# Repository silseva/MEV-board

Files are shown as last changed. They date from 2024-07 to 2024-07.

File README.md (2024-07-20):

# MEV board

Design files of the controller board used in the proof-of-concept setup of the [Multiple Emergency Ventilator project](https://mev.deib.polimi.it/).

The board has been designed to be coupled with an STM32F429 discovery board from ST Microelectronics (STM32F429I-DISC1) and serves a double puropose:
* controller for the closed-loop system regulating the bell-jar level;
* controller for the inspiration/expiration valves at bed side.

The design files are released in the Kicad 8.0 format under the [Creative Commons BY-NC-SA 4.0 license](https://creativecommons.org/licenses/by-nc-sa/4.0/).

**DISCLAIMER:** the hardware design made available in this repository has been made for a proof-of-concept setup. Therefore, it must not be considered safe for clinical use.

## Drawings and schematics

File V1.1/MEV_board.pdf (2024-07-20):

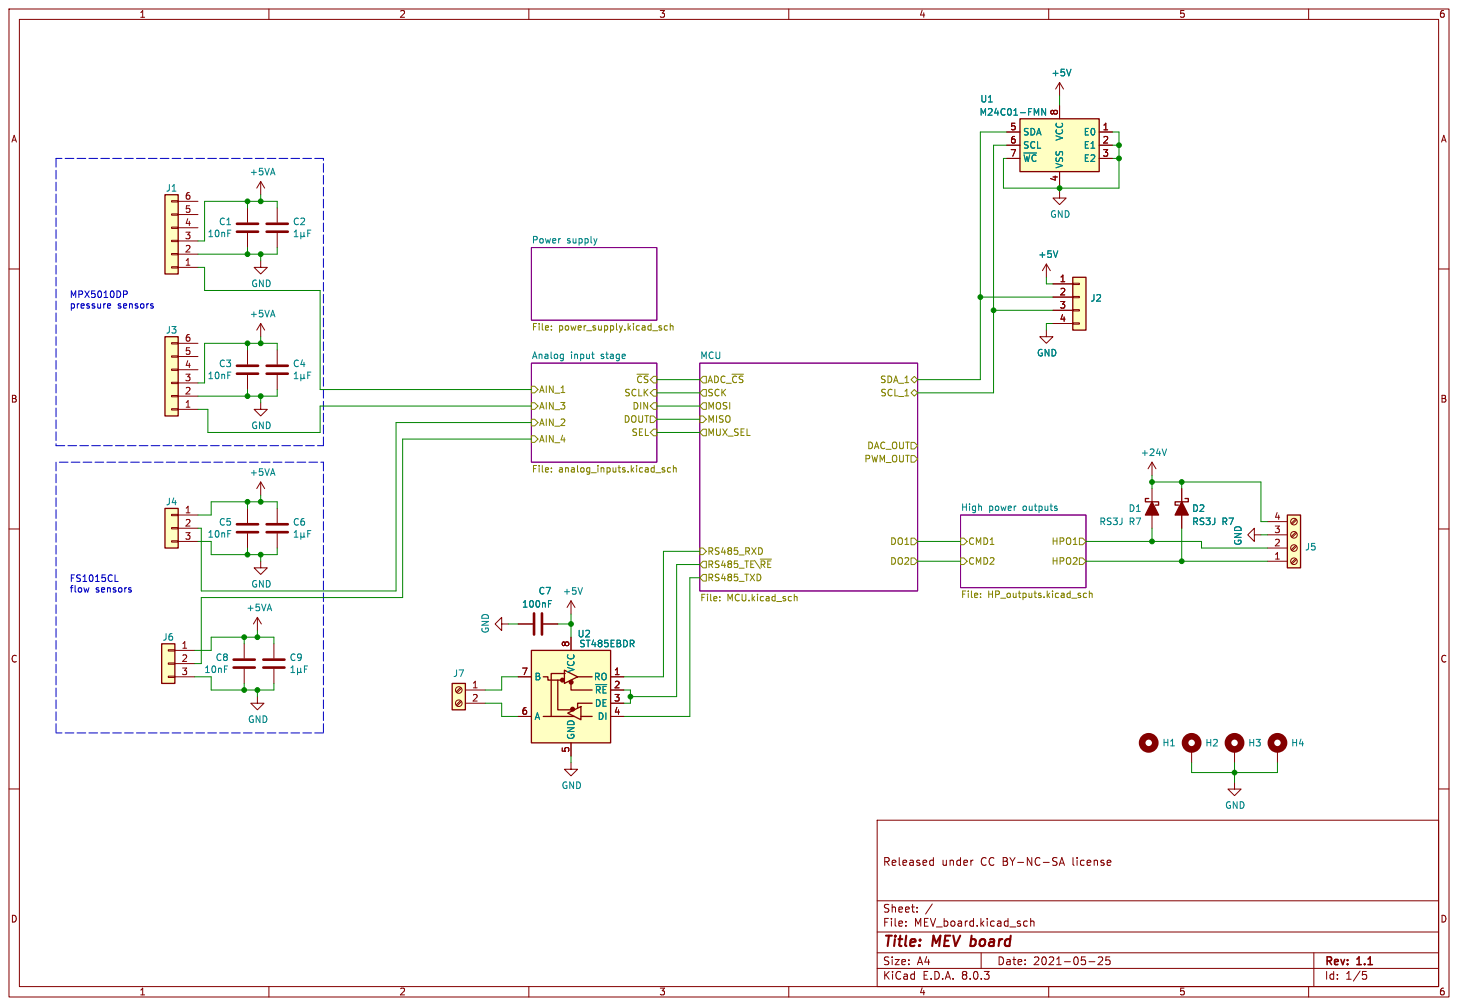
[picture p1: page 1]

SEL AIN_3 AIN_4 Analog input stage File: analog_inputs.kicad_sch Power supply File: power_supply.kicad_sch

SCL_1 SDA_1 SCK MOSI ADC_~{CS} MISO

Id: 1/5 Title: MEV board

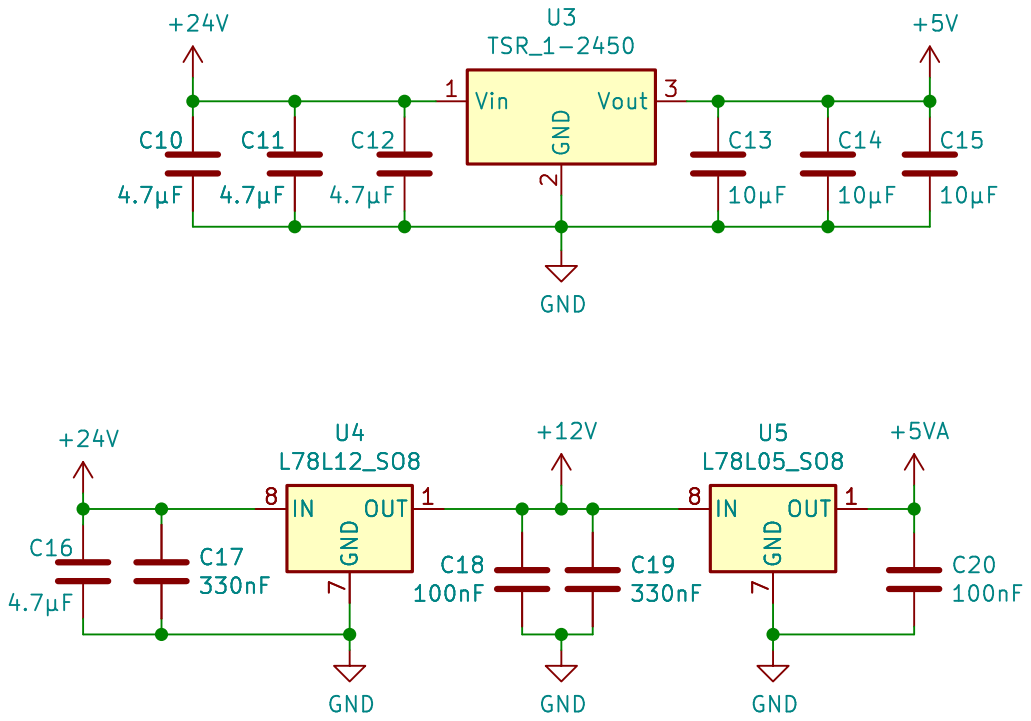
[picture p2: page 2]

Id: 2/5 Title: Power Supply

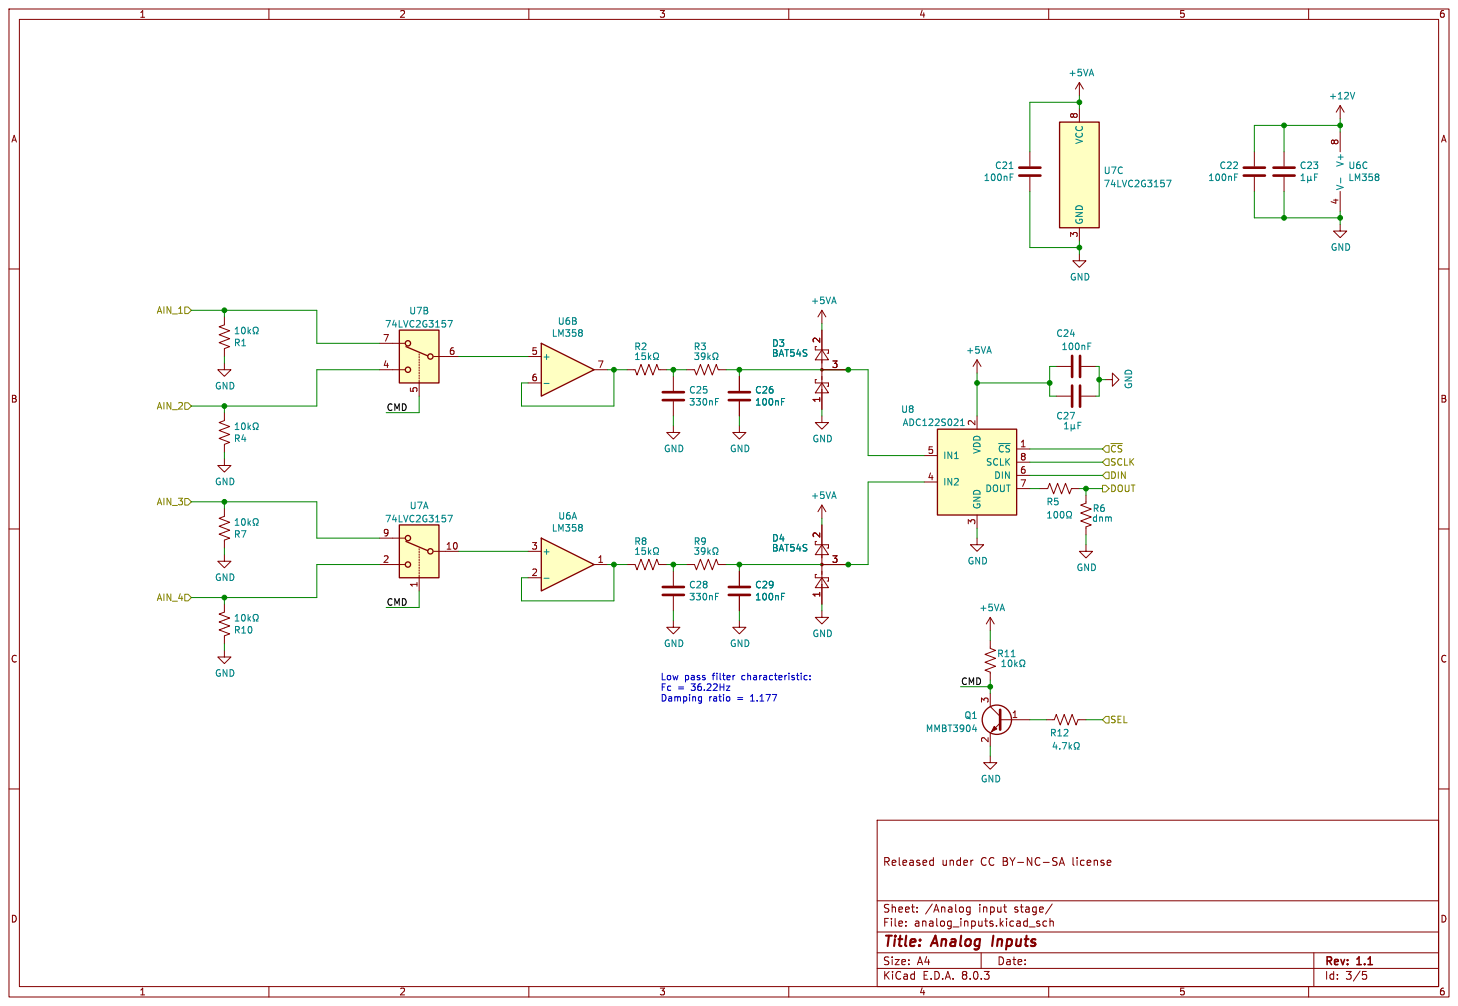
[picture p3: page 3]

Id: 3/5 Title: Analog Inputs

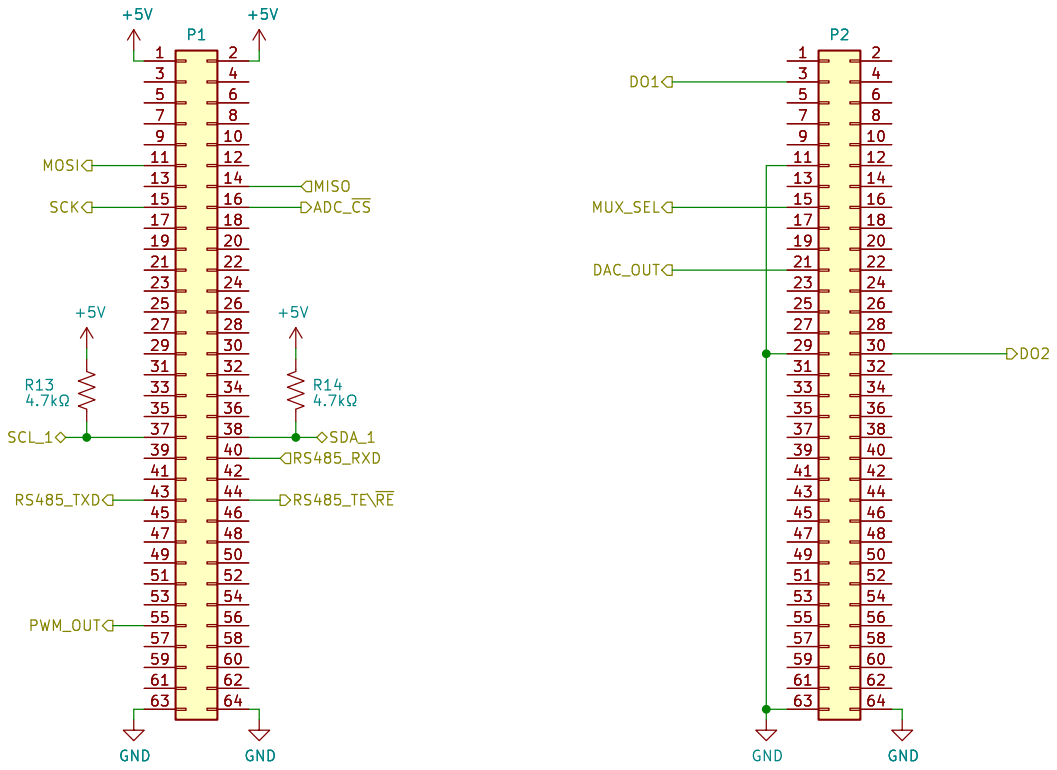
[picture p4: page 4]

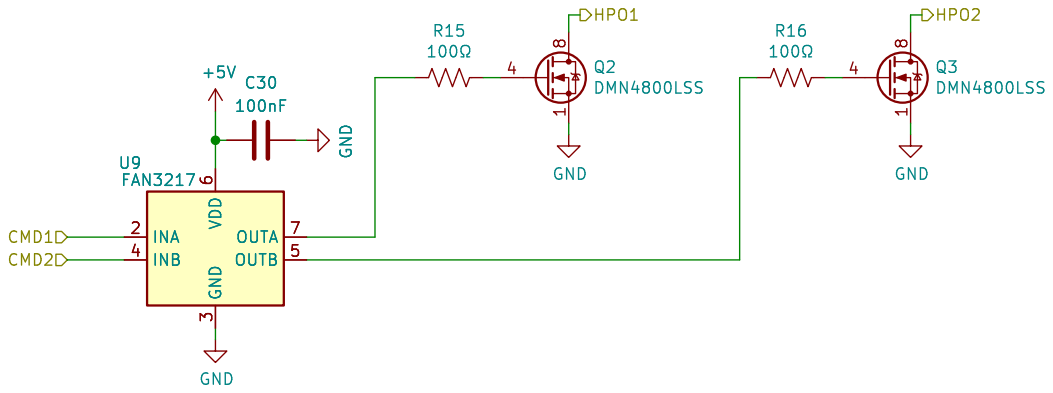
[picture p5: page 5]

Id: 5/5 Title: High Power Outputs

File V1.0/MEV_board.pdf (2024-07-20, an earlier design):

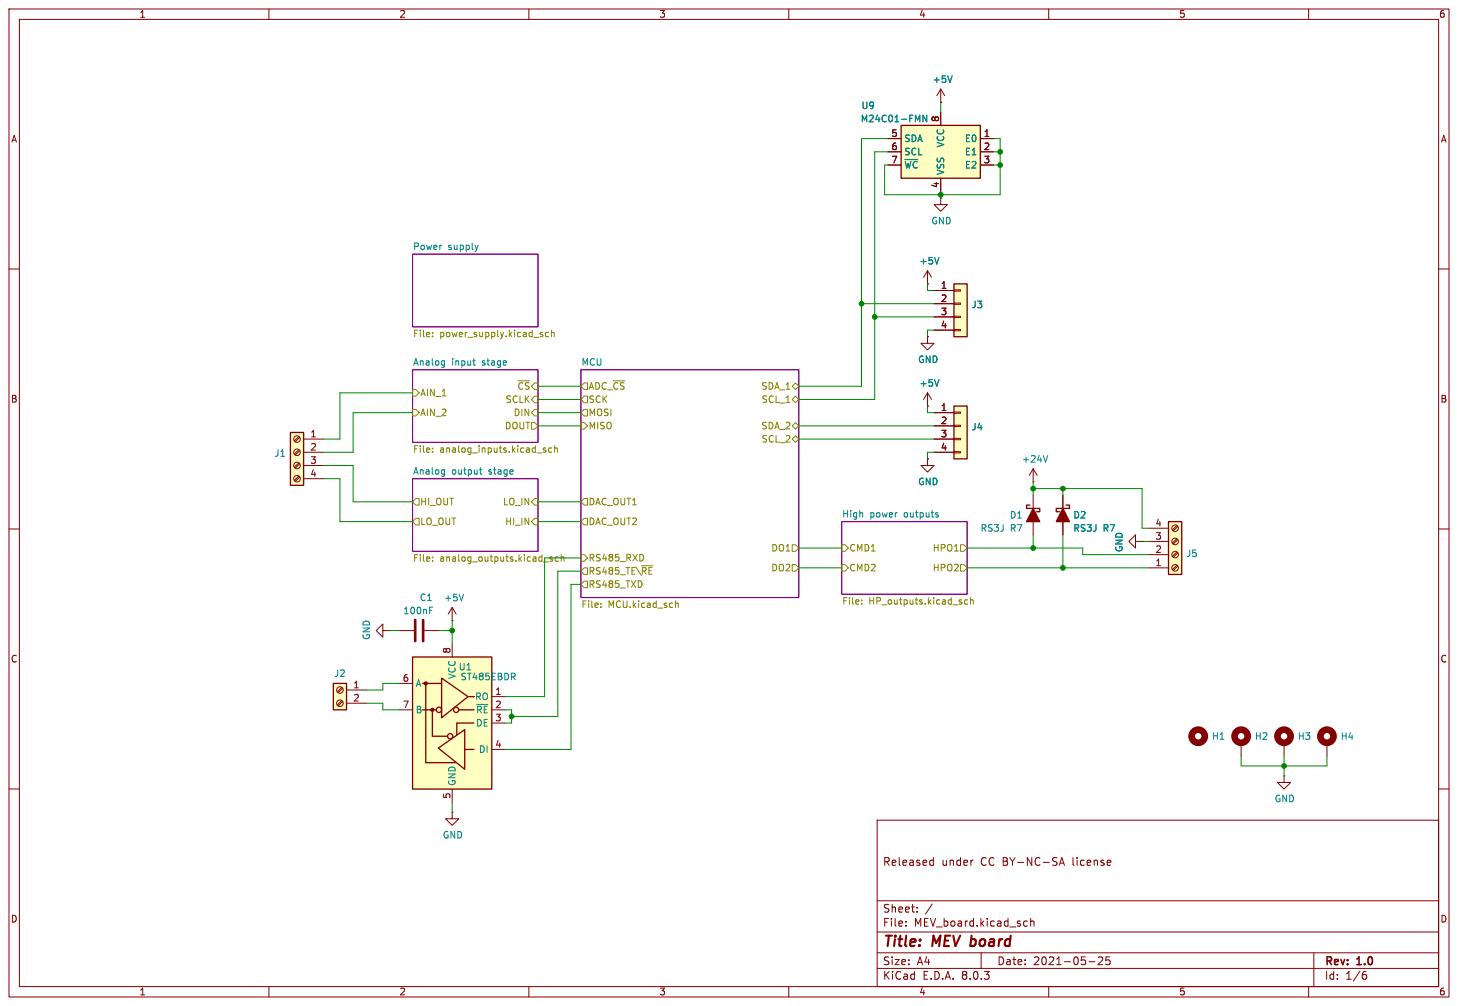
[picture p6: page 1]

Analog input stage File: analog_inputs.kicad_sch

Id: 1/6 Title: MEV board

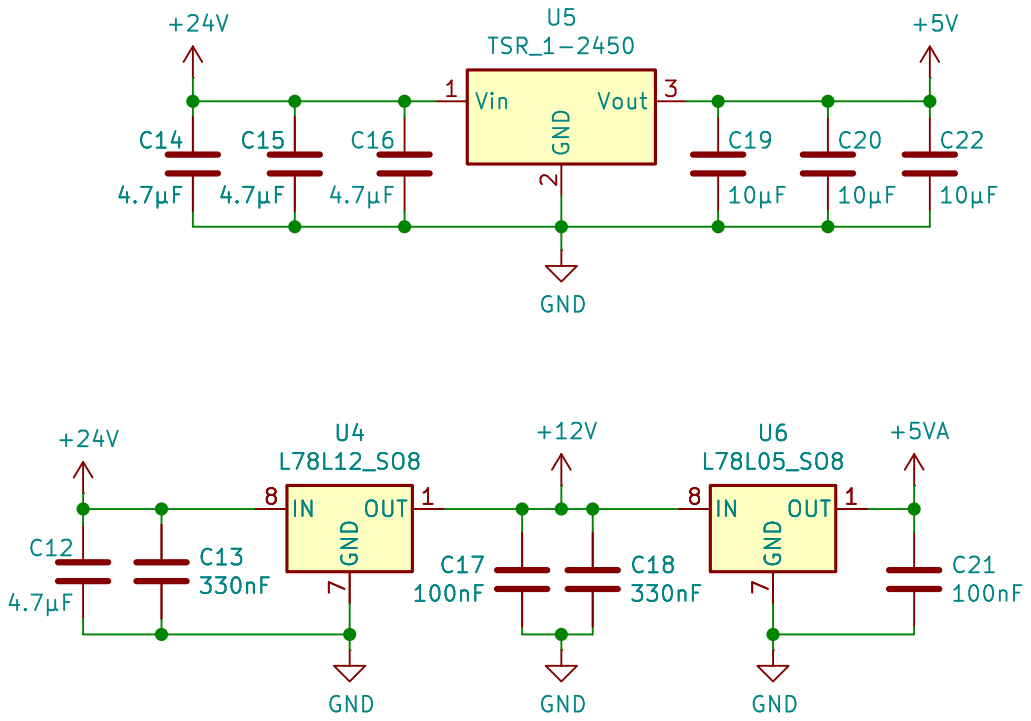
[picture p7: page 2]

Id: 2/6 Title: Power Supply

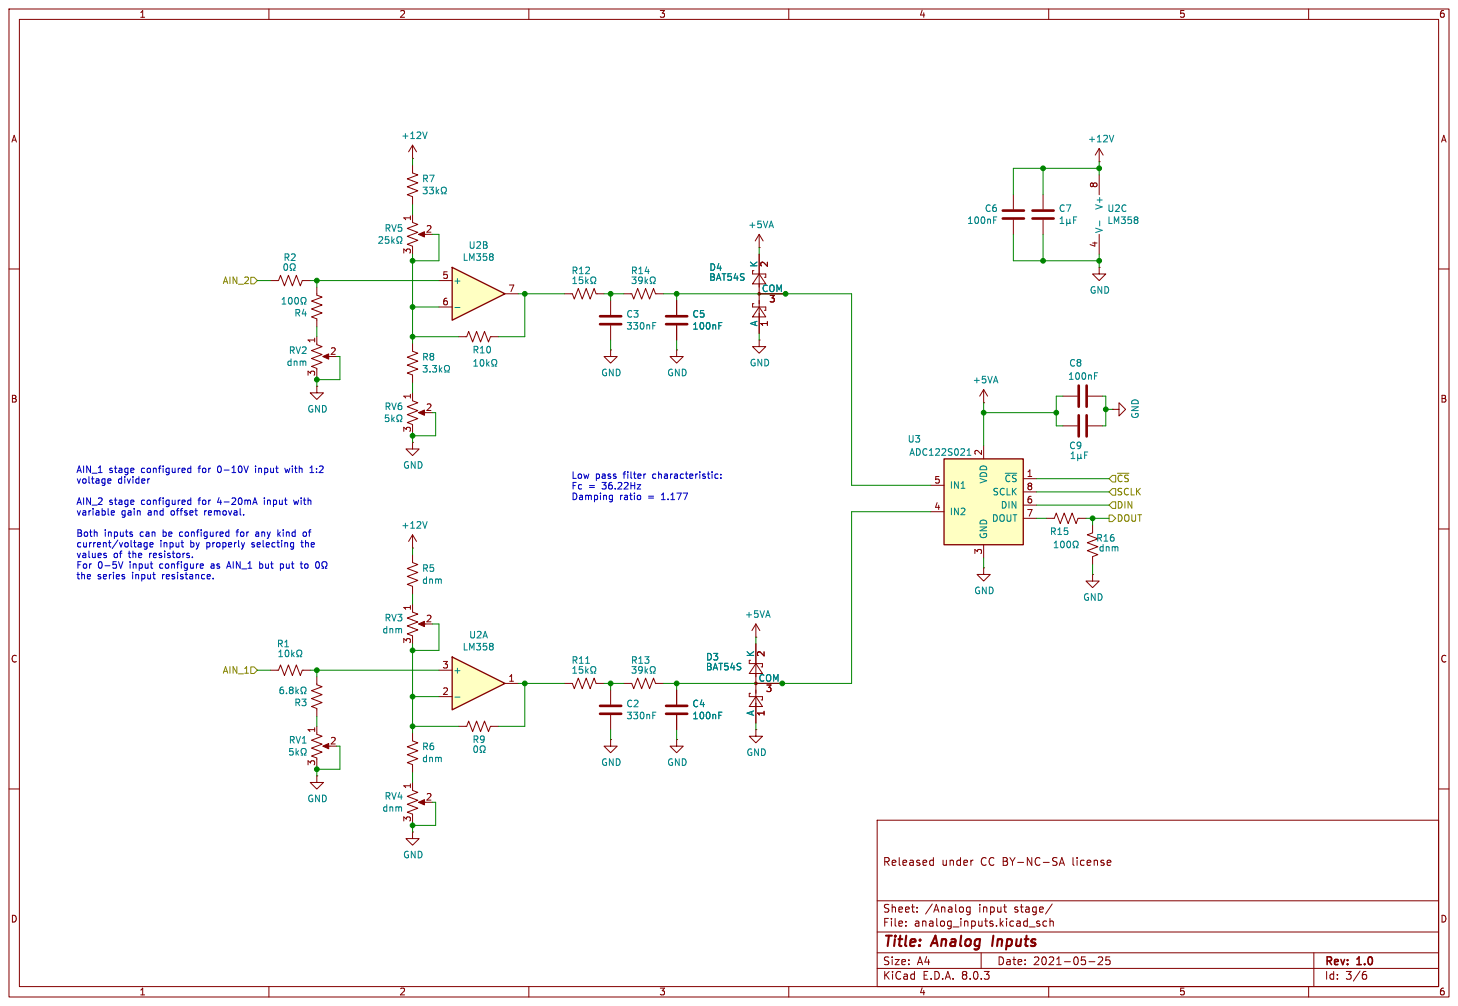
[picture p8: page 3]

Id: 3/6 Title: Analog Inputs

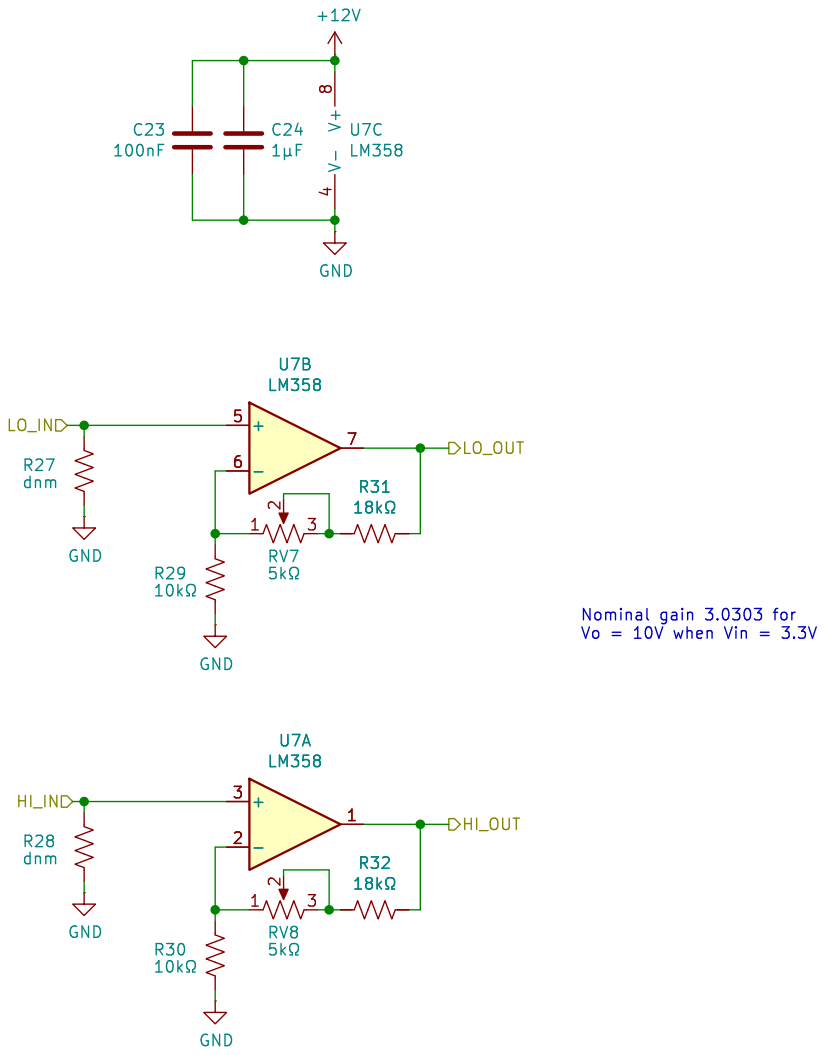
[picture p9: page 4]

Nominal gain 3.0303 for Vo = 10V when Vin = 3.3V U7B

Id: 4/6 Title: Analog Outputs

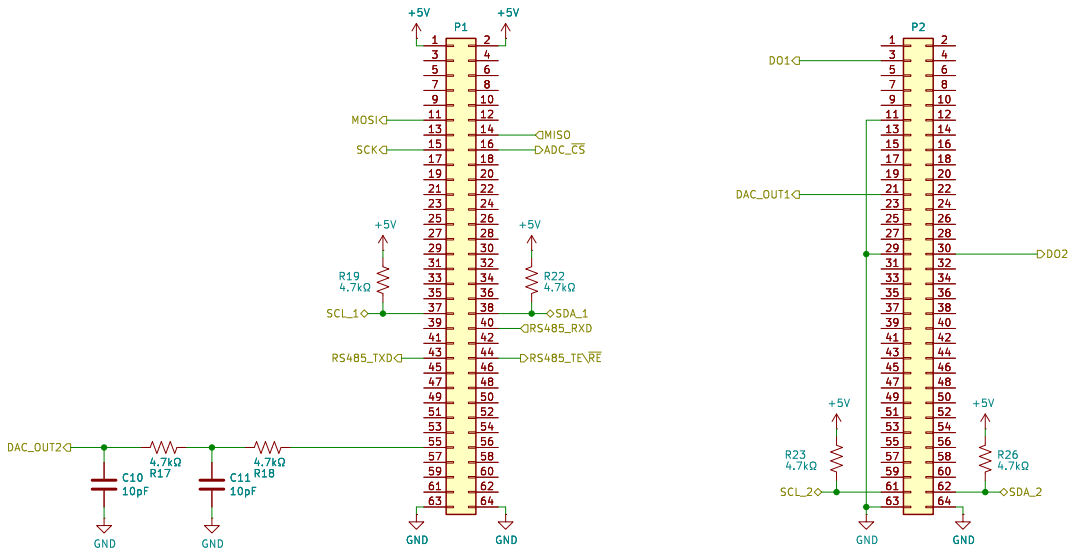
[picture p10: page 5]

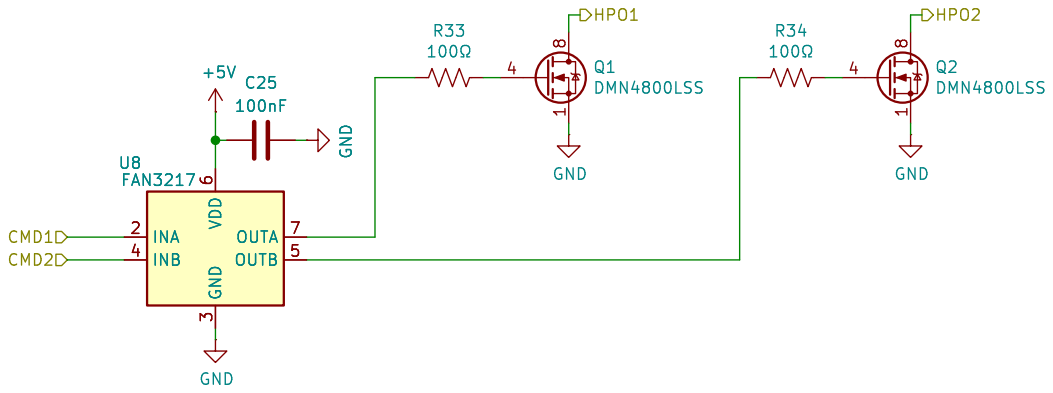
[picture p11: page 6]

Id: 6/6 Title: High Power Outputs

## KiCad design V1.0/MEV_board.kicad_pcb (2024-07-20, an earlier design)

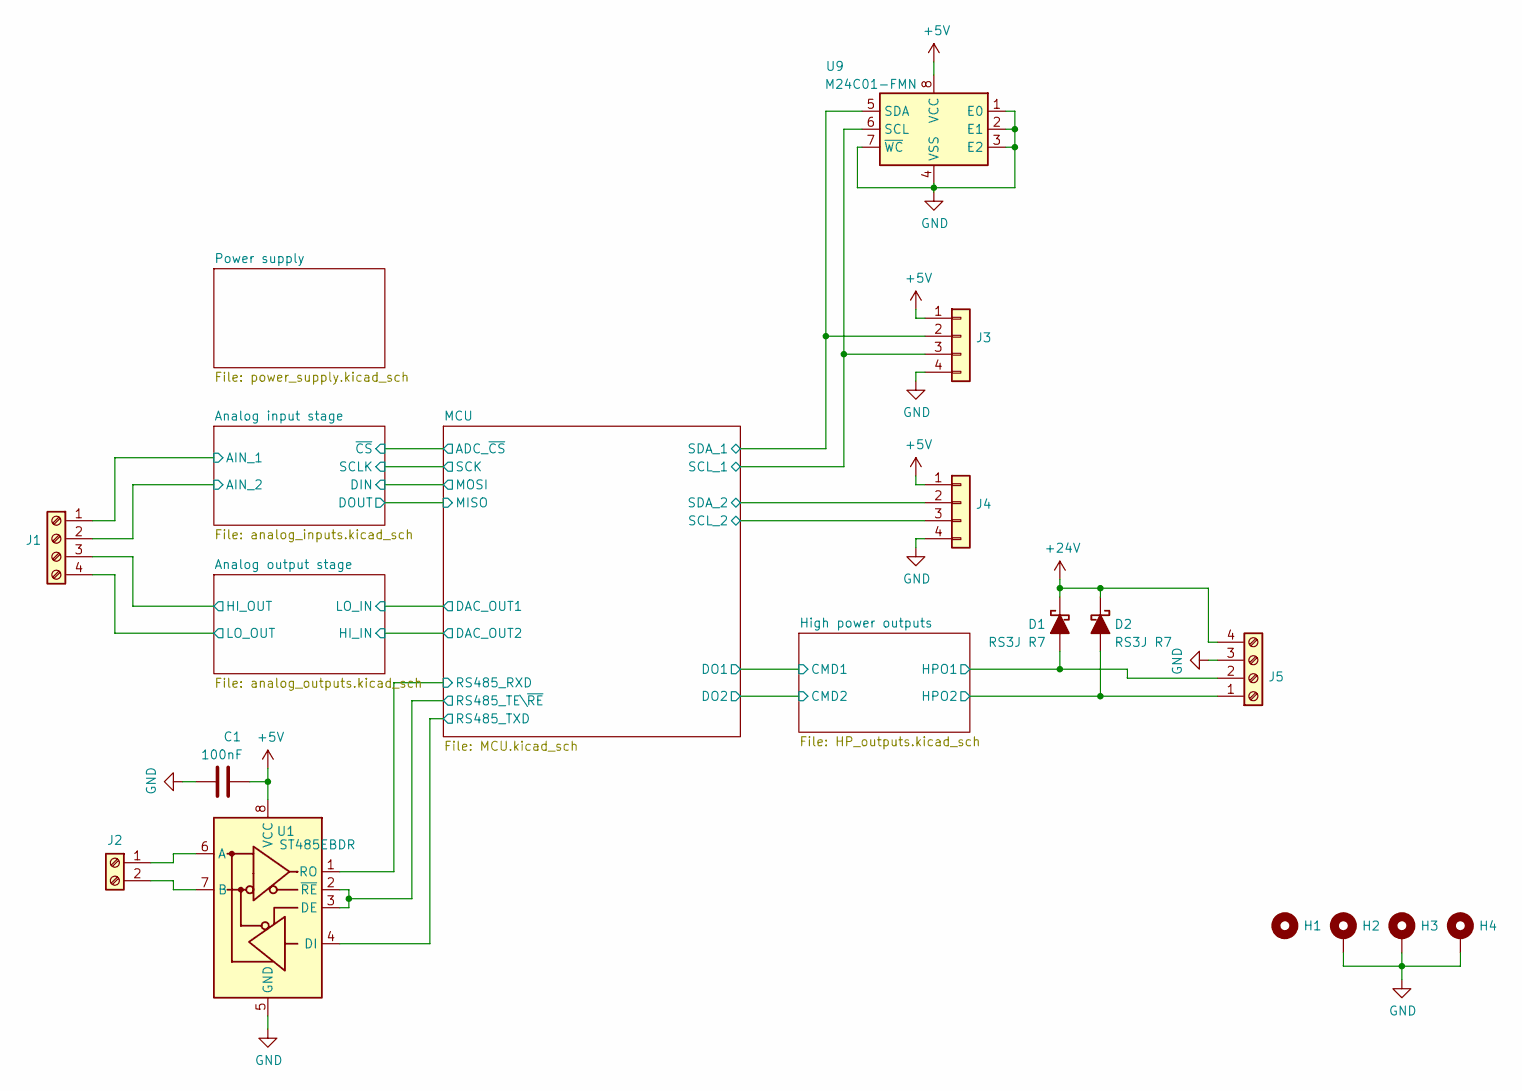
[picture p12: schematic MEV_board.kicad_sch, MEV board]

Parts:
C1: 100nF; C_0603_1608Metric_Pad1.08x0.95mm_HandSolder
D1, D2: RS3J R7; D_SMC_Handsoldering
H1, H2, H3, H4: MountingHole_3.2mm_M3_Pad_TopBottom
J1, J5: TerminalBlock_Phoenix_MKDS-1,5-4-5.08_1x04_P5.08mm_Horizont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
J2: TerminalBlock_Phoenix_MKDS-1,5-2-5.08_1x02_P5.08mm_Horizont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
J3, J4: PinHeader_1x04_P2.54mm_Vertical
U1: ST485EBDR; SOIC-8_3.9x4.9mm_P1.27mm
U9: M24C01-FMN; SOIC-8_3.9x4.9mm_P1.27mm

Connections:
+5V: C1.1, J3.1, J4.1, U1.8 (VCC), U9.8 (VCC); also elsewhere on the board
+24V: D1.1 (K), D2.1 (K), J5.4; also elsewhere on the board
/Analog input stage/AIN_1: J1.1; also elsewhere on the board
/Analog input stage/AIN_2: J1.2; also elsewhere on the board
/Analog output stage/HI_OUT: J1.3; also elsewhere on the board
/Analog output stage/LO_OUT: J1.4; also elsewhere on the board
/High power outputs/HPO1: D1.2 (A), J5.2; also elsewhere on the board
/High power outputs/HPO2: D2.2 (A), J5.1; also elsewhere on the board
/MCU/RS485_RXD: U1.1 (RO); also elsewhere on the board
/MCU/RS485_TE\~RE: U1.2 (~RE), U1.3 (DE); also elsewhere on the board
/MCU/RS485_TXD: U1.4 (DI); also elsewhere on the board
/MCU/SCL_1: J3.3, U9.6 (SCL); also elsewhere on the board
/MCU/SCL_2: J4.3; also elsewhere on the board
/MCU/SDA_1: J3.2, U9.5 (SDA); also elsewhere on the board
/MCU/SDA_2: J4.2; also elsewhere on the board
GND: C1.2, H2.1, H3.1, H4.1, J3.4, J4.4, J5.3, U1.5 (GND), U9.1 (E0), U9.2 (E1), U9.3 (E2), U9.4 (VSS), U9.7 (~WC); also elsewhere on the board

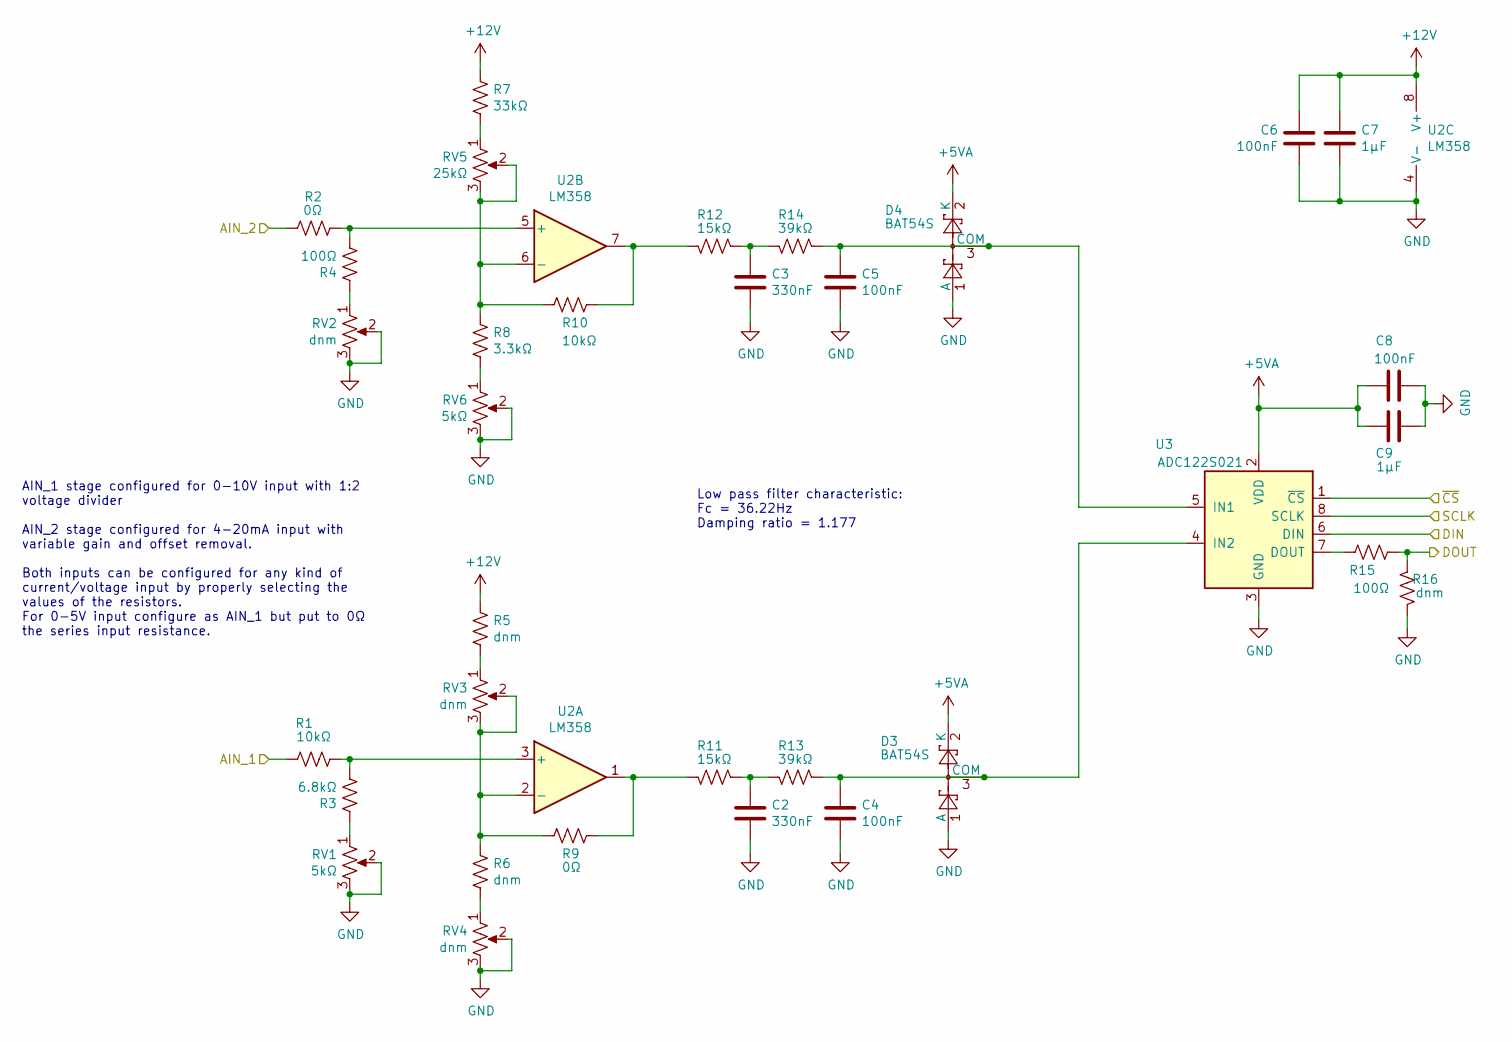
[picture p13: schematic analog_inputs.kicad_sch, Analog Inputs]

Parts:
C2, C3: 330nF; C_0805_2012Metric_Pad1.18x1.45mm_HandSolder
C4, C5: 100nF; C_0805_2012Metric_Pad1.18x1.45mm_HandSolder
C6, C8: 100nF; C_0603_1608Metric_Pad1.08x0.95mm_HandSolder
C7, C9: 1μF; C_0603_1608Metric_Pad1.08x0.95mm_HandSolder
D3, D4: BAT54S; SOT-23
R1, R10: 10kΩ; R_0805_2012Metric_Pad1.20x1.40mm_HandSolder
R2, R9: 0Ω; R_0805_2012Metric_Pad1.20x1.40mm_HandSolder
R3: 6.8kΩ; R_0805_2012Metric_Pad1.20x1.40mm_HandSolder
R4: 100Ω; R_0805_2012Metric_Pad1.20x1.40mm_HandSolder
R5, R6, R16: dnm; R_0805_2012Metric_Pad1.20x1.40mm_HandSolder
R7: 33kΩ; R_0805_2012Metric_Pad1.20x1.40mm_HandSolder
R8: 3.3kΩ; R_0805_2012Metric_Pad1.20x1.40mm_HandSolder
R11, R12: 15kΩ; R_0603_1608Metric_Pad0.98x0.95mm_HandSolder
R13, R14: 39kΩ; R_0603_1608Metric_Pad0.98x0.95mm_HandSolder
R15: 100Ω; R_0603_1608Metric_Pad0.98x0.95mm_HandSolder
RV1, RV6: 5kΩ; Potentiometer_Bourns_3296W_Vertical
RV2, RV3, RV4: dnm; Potentiometer_Bourns_3296W_Vertical
RV5: 25kΩ; Potentiometer_Bourns_3296W_Vertical
U2: LM358; SOIC-8_3.9x4.9mm_P1.27mm
U3: ADC122S021; VSSOP-8_3.0x3.0mm_P0.65mm

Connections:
+5VA: C8.1, C9.1, D3.2 (K), D4.2 (K), U3.2 (VDD); also elsewhere on the board
+12V: C6.2, C7.1, R5.1, R7.1, U2.8 (V+); also elsewhere on the board
/Analog input stage/AIN_1: R1.1; also elsewhere on the board
/Analog input stage/AIN_2: R2.1; also elsewhere on the board
/Analog input stage/DIN: U3.6 (DIN); also elsewhere on the board
/Analog input stage/DOUT: R15.2, R16.1; also elsewhere on the board
/MCU/ADC_~CS: U3.1 (~CS); also elsewhere on the board
/MCU/SCK: U3.8 (SCLK); also elsewhere on the board
GND: C2.2, C3.2, C4.2, C5.2, C6.1, C7.2, C8.2, C9.2, D3.1 (A), D4.1 (A), R16.2, RV1.2, RV1.3, RV2.2, RV2.3, RV4.2, RV4.3, RV6.2, RV6.3, U2.4 (V-), U3.3 (GND); also elsewhere on the board
unnamed: C2.1, R11.1, R13.2
unnamed: C3.1, R12.1, R14.2
unnamed: C4.1, D3.3 (COM), R13.1, U3.4 (IN2)
unnamed: C5.1, D4.3 (COM), R14.1, U3.5 (IN1)
unnamed: R1.2, R3.2, U2.3 (+)
unnamed: R2.2, R4.2, U2.5 (+)
unnamed: R3.1, RV1.1
unnamed: R4.1, RV2.1
unnamed: R5.2, RV3.1
unnamed: R6.1, R9.2, RV3.2, RV3.3, U2.2 (-)
unnamed: R6.2, RV4.1
unnamed: R7.2, RV5.1
unnamed: R8.2, RV6.1
unnamed: R10.1, R12.2, U2.7
unnamed: R8.1, R10.2, RV5.2, RV5.3, U2.6 (-)
unnamed: R9.1, R11.2, U2.1
unnamed: R15.1, U3.7 (DOUT)

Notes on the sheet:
AIN_1 stage configured for 0-10V input with 1:2 voltage divider AIN_2 stage configured for 4-20mA input with variable gain and offset removal. Both inputs can be configured for any kind of current/voltage input by properly selecting the values of the resistors. For 0-5V input configure as AIN_1 but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
Low pass filter characteristic: Fc = 36.22Hz Damping ratio = 1.177

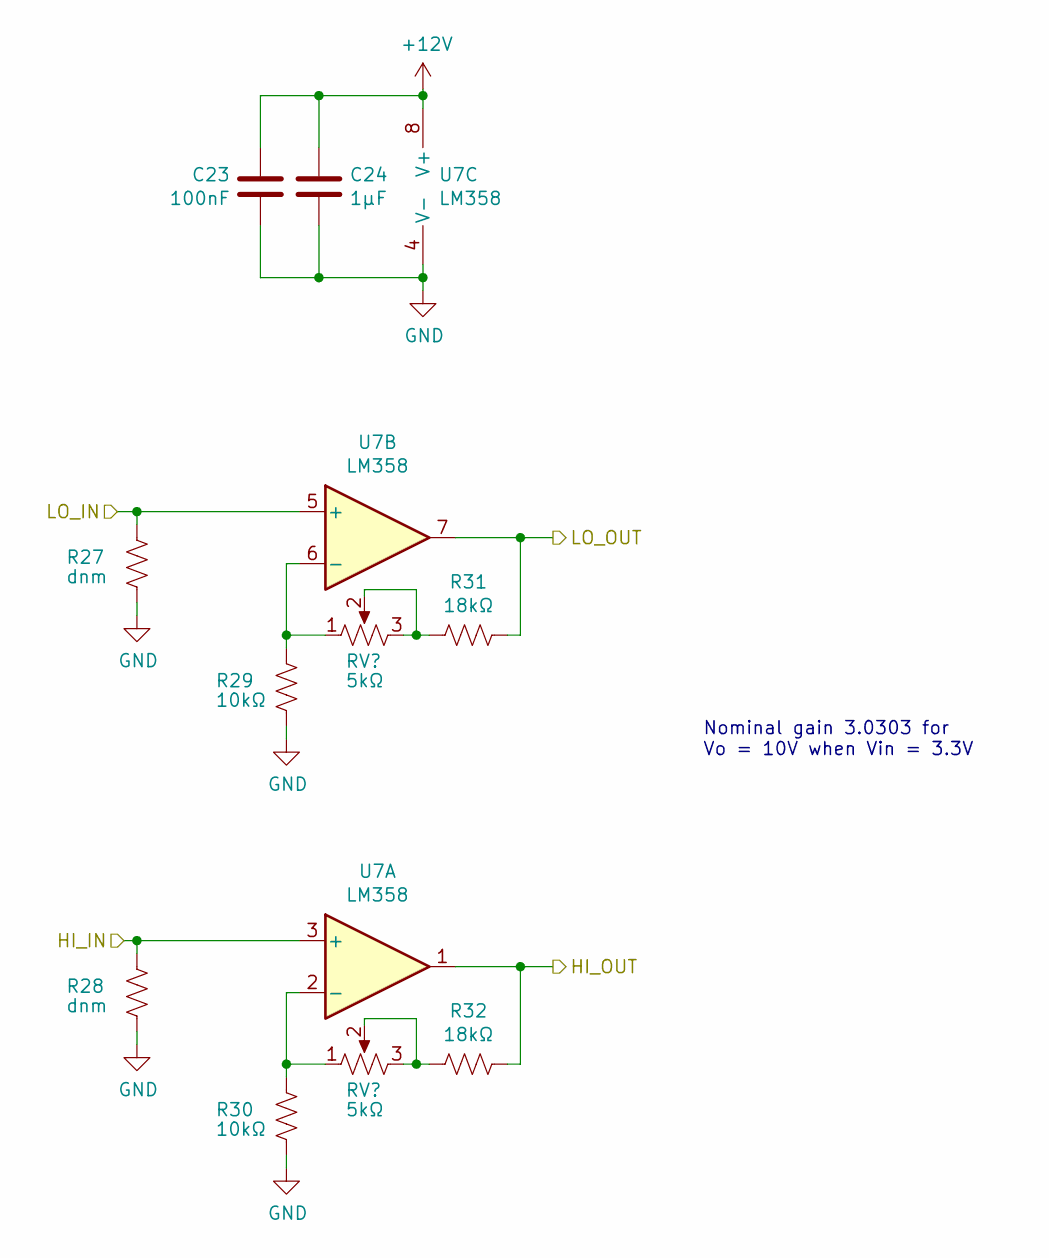
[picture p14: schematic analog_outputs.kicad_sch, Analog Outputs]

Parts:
C23: 100nF; C_0603_1608Metric_Pad1.08x0.95mm_HandSolder
C24: 1μF; C_0603_1608Metric_Pad1.08x0.95mm_HandSolder
R27, R28: dnm; R_0805_2012Metric_Pad1.20x1.40mm_HandSolder
R29, R30: 10kΩ; R_0805_2012Metric_Pad1.20x1.40mm_HandSolder
R31, R32: 18kΩ; R_0805_2012Metric_Pad1.20x1.40mm_HandSolder
RV7, RV8: 5kΩ; Potentiometer_Bourns_3296W_Vertical
U7: LM358; SOIC-8_3.9x4.9mm_P1.27mm

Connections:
+12V: C23.2, C24.1, U7.8 (V+); also elsewhere on the board
/Analog output stage/HI_OUT: R32.1, U7.1; also elsewhere on the board
/Analog output stage/LO_OUT: R31.1, U7.7; also elsewhere on the board
/MCU/DAC_OUT1: R27.1, U7.5 (+); also elsewhere on the board
/MCU/DAC_OUT2: R28.1, U7.3 (+); also elsewhere on the board
GND: C23.1, C24.2, R27.2, R28.2, R29.2, R30.2, U7.4 (V-); also elsewhere on the board
unnamed: R29.1, RV7.1, U7.6 (-)
unnamed: R30.1, RV8.1, U7.2 (-)
unnamed: R31.2, RV7.2, RV7.3
unnamed: R32.2, RV8.2, RV8.3

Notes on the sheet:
Nominal gain 3.0303 for Vo = 10V when Vin = 3.3V

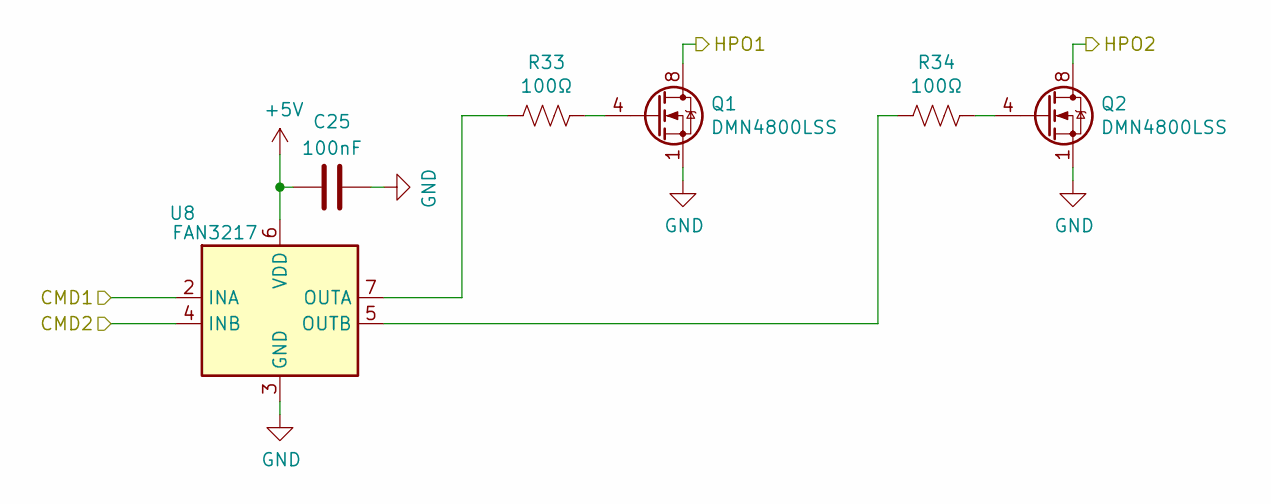
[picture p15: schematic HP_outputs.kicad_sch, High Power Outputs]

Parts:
C25: 100nF; C_0603_1608Metric_Pad1.08x0.95mm_HandSolder
Q1, Q2: DMN4800LSS; SOIC-8_3.9x4.9mm_P1.27mm
R33, R34: 100Ω; R_0603_1608Metric_Pad0.98x0.95mm_HandSolder
U8: FAN3217; SOIC-8_3.9x4.9mm_P1.27mm

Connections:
+5V: C25.1, U8.6 (VDD); also elsewhere on the board
/High power outputs/CMD1: U8.2 (INA); also elsewhere on the board
/High power outputs/CMD2: U8.4 (INB); also elsewhere on the board
/High power outputs/HPO1: Q1.5 (D), Q1.6 (D), Q1.7 (D), Q1.8 (D); also elsewhere on the board
/High power outputs/HPO2: Q2.5 (D), Q2.6 (D), Q2.7 (D), Q2.8 (D); also elsewhere on the board
GND: C25.2, Q1.1 (S), Q1.2 (S), Q1.3 (S), Q2.1 (S), Q2.2 (S), Q2.3 (S), U8.3 (GND); also elsewhere on the board
unnamed: Q1.4 (G), R33.1
unnamed: Q2.4 (G), R34.1
unnamed: R33.2, U8.7 (OUTA)
unnamed: R34.2, U8.5 (OUTB)

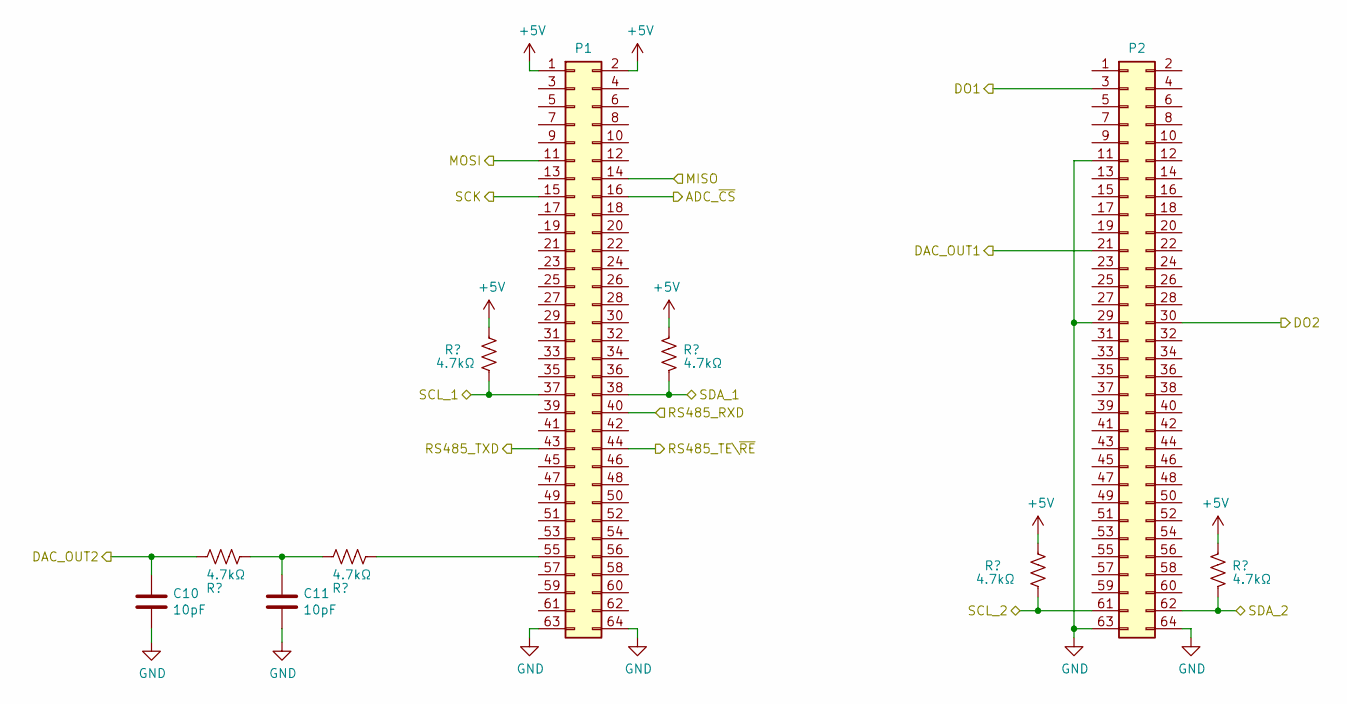
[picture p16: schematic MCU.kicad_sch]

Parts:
C10, C11: 10pF; C_0805_2012Metric_Pad1.18x1.45mm_HandSolder
P1, P2: PinHeader_2x32_P2.54mm_Vertical
R17, R18, R19, R22, R23, R26: 4.7kΩ; R_0603_1608Metric_Pad0.98x0.95mm_HandSolder

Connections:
+5V: P1.1, P1.2, R19.2, R22.2, R23.2, R26.2; also elsewhere on the board
/Analog input stage/DIN: P1.11; also elsewhere on the board
/Analog input stage/DOUT: P1.14; also elsewhere on the board
/High power outputs/CMD1: P2.3; also elsewhere on the board
/High power outputs/CMD2: P2.30; also elsewhere on the board
/MCU/ADC_~CS: P1.16; also elsewhere on the board
/MCU/DAC_OUT1: P2.21; also elsewhere on the board
/MCU/DAC_OUT2: C10.1, R17.2; also elsewhere on the board
/MCU/RS485_RXD: P1.40; also elsewhere on the board
/MCU/RS485_TE\~RE: P1.44; also elsewhere on the board
/MCU/RS485_TXD: P1.43; also elsewhere on the board
/MCU/SCK: P1.15; also elsewhere on the board
/MCU/SCL_1: P1.37, R19.1; also elsewhere on the board
/MCU/SCL_2: P2.61, R23.1; also elsewhere on the board
/MCU/SDA_1: P1.38, R22.1; also elsewhere on the board
/MCU/SDA_2: P2.62, R26.1; also elsewhere on the board
GND: C10.2, C11.2, P1.63, P1.64, P2.11, P2.29, P2.63, P2.64; also elsewhere on the board
unnamed: C11.1, R17.1, R18.2
unnamed: P1.55, R18.1

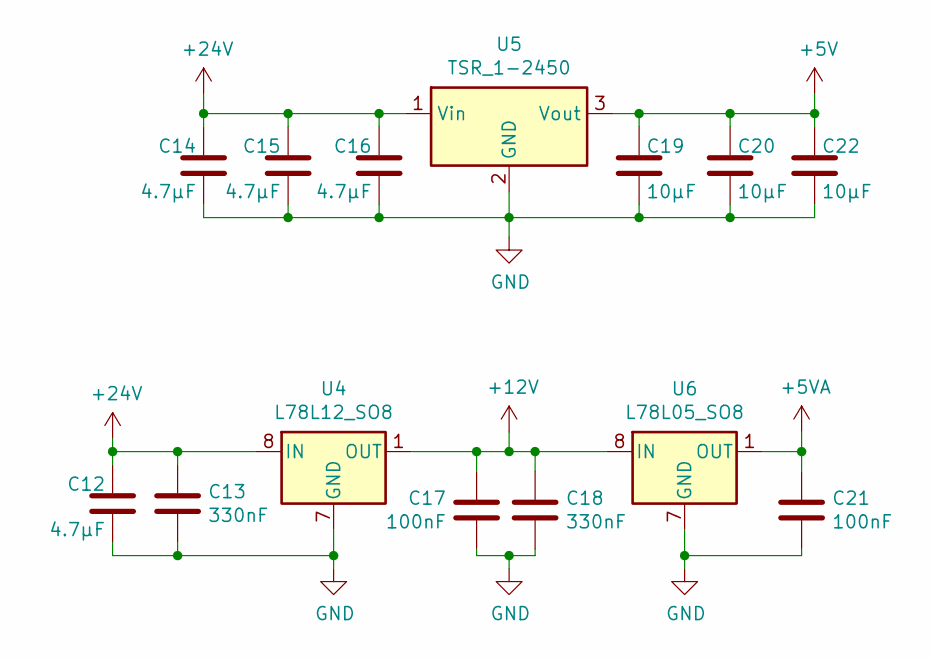
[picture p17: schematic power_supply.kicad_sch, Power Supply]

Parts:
C12, C14, C15, C16: 4.7μF; C_0805_2012Metric_Pad1.18x1.45mm_HandSolder
C13, C18: 330nF; C_0805_2012Metric_Pad1.18x1.45mm_HandSolder
C17, C21: 100nF; C_0603_1608Metric_Pad1.08x0.95mm_HandSolder
C19, C20, C22: 10μF; C_0805_2012Metric_Pad1.18x1.45mm_HandSolder
U4: L78L12_SO8; SOIC-8_3.9x4.9mm_P1.27mm
U5: TSR_1-2450; Converter_DCDC_TRACO_TSR-1_THT
U6: L78L05_SO8; SOIC-8_3.9x4.9mm_P1.27mm

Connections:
+5V: C19.2, C20.2, C22.2, U5.3 (Vout); also elsewhere on the board
+5VA: C21.2, U6.1 (OUT); also elsewhere on the board
+12V: C17.2, C18.2, U4.1 (OUT), U6.8 (IN); also elsewhere on the board
+24V: C12.2, C13.2, C14.2, C15.2, C16.2, U4.8 (IN), U5.1 (Vin); also elsewhere on the board
GND: C12.1, C13.1, C14.1, C15.1, C16.1, C17.1, C18.1, C19.1, C20.1, C21.1, C22.1, U4.2 (GND), U4.3 (GND), U4.6 (GND), U4.7 (GND), U5.2 (GND), U6.2 (GND), U6.3 (GND), U6.6 (GND), U6.7 (GND); also elsewhere on the board

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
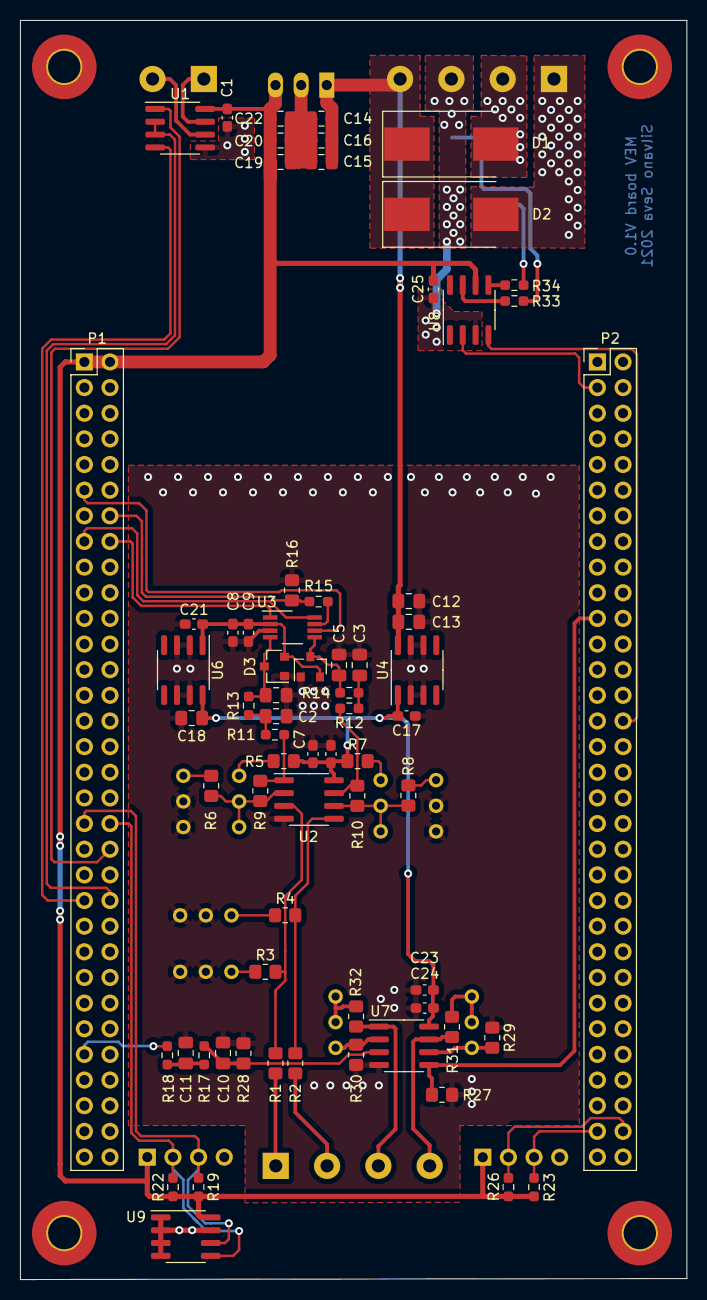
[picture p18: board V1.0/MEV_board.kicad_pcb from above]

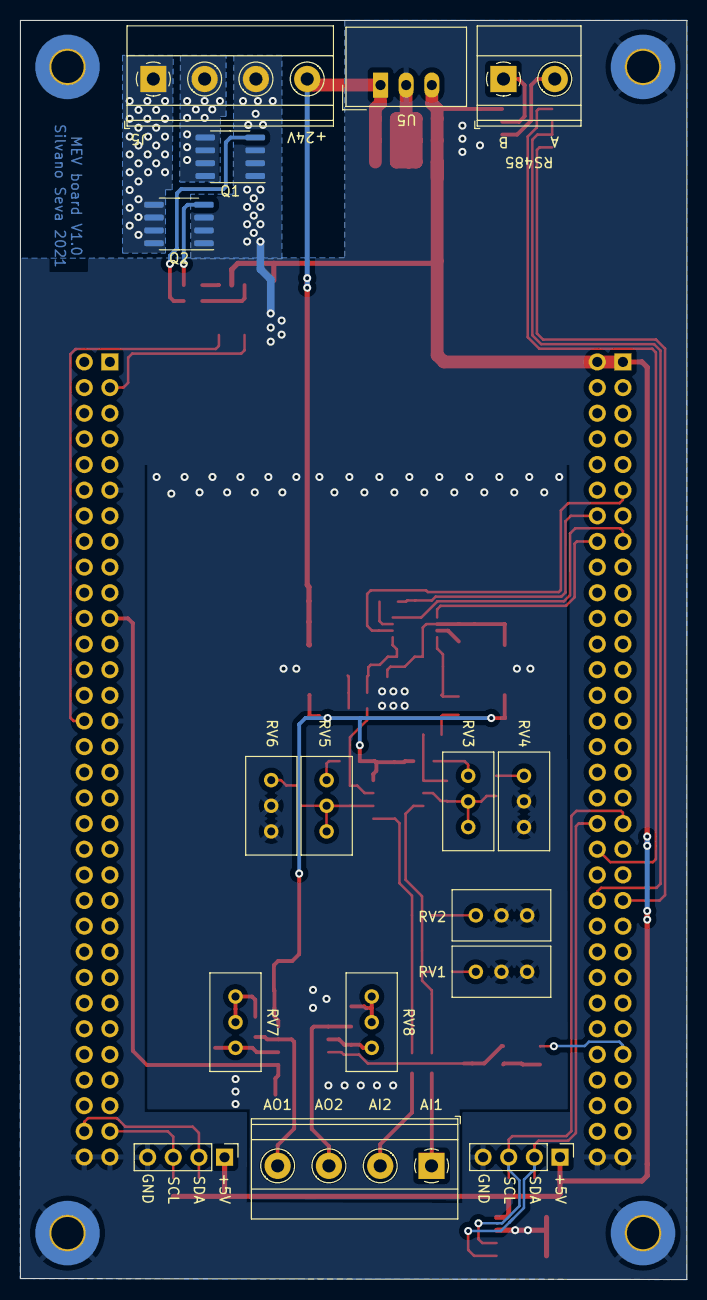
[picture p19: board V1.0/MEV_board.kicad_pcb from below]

Board: 2 copper layers, 66.0 x 124.7 mm, 89 parts (16 on the bottom side), 55 nets.

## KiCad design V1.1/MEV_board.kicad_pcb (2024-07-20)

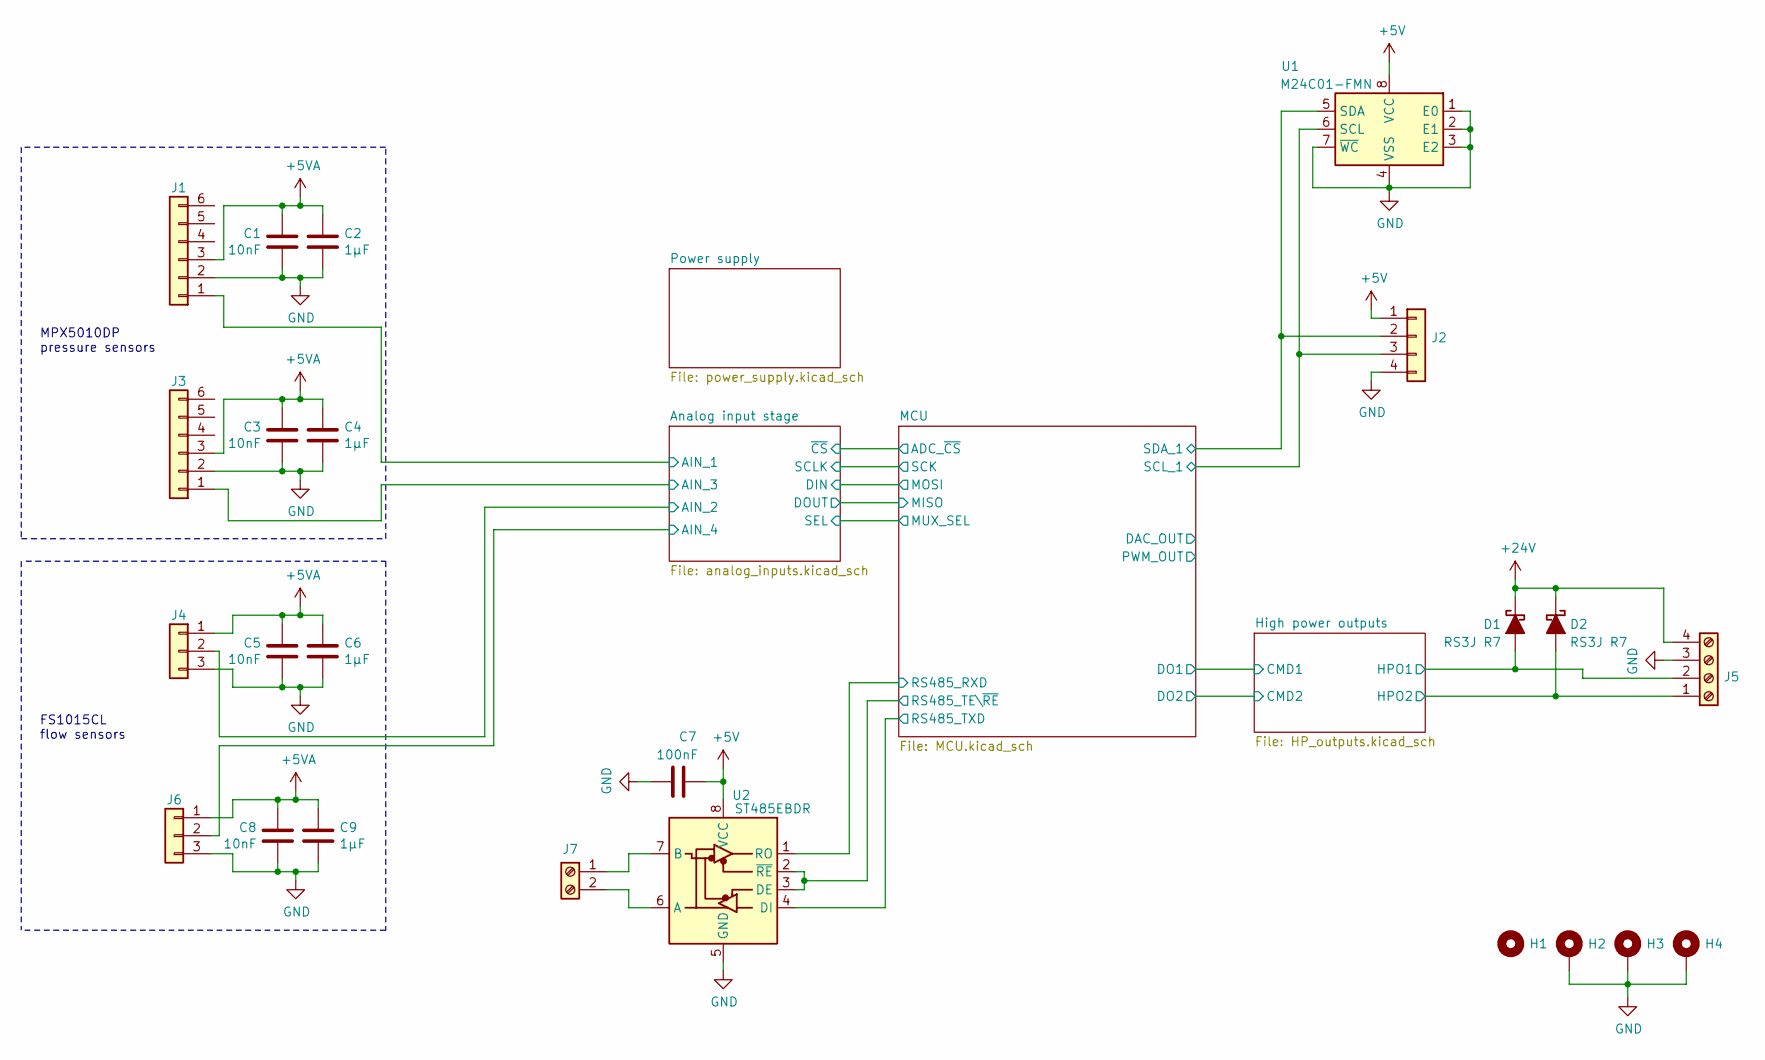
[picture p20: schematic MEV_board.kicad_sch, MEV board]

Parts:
C1, C3, C5, C8: 10nF; C_0603_1608Metric_Pad1.08x0.95mm_HandSolder
C2, C4, C6, C9: 1μF; C_0603_1608Metric_Pad1.08x0.95mm_HandSolder
C7: 100nF; C_0603_1608Metric_Pad1.08x0.95mm_HandSolder
D1, D2: RS3J R7; D_SMC_Handsoldering
H1, H2, H3, H4: MountingHole_3.2mm_M3_Pad_TopBottom
J1, J3: PinSocket_1x06_P2.54mm_Vertical
J2: PinHeader_1x04_P2.54mm_Vertical
J4, J6: Molex_KK-254_AE-6410-03A_1x03_P2.54mm_Vertical
J5: TerminalBlock_Phoenix_MKDS-1,5-4-5.08_1x04_P5.08mm_Horizont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
J7: TerminalBlock_Phoenix_MKDS-1,5-2-5.08_1x02_P5.08mm_Horizont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
U1: M24C01-FMN; SOIC-8_3.9x4.9mm_P1.27mm
U2: ST485EBDR; SOIC-8_3.9x4.9mm_P1.27mm

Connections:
+5V: C7.1, J2.1, U1.8 (VCC), U2.8 (VCC); also elsewhere on the board
+5VA: C1.2, C2.1, C3.2, C4.1, C5.2, C6.1, C8.2, C9.1, J1.3, J3.3, J4.1, J6.1; also elsewhere on the board
+24V: D1.1 (K), D2.1 (K), J5.4; also elsewhere on the board
/Analog input stage/AIN_1: J1.1; also elsewhere on the board
/Analog input stage/AIN_2: J4.2; also elsewhere on the board
/Analog input stage/AIN_3: J3.1; also elsewhere on the board
/Analog input stage/AIN_4: J6.2; also elsewhere on the board
/High power outputs/HPO1: D1.2 (A), J5.2; also elsewhere on the board
/High power outputs/HPO2: D2.2 (A), J5.1; also elsewhere on the board
/MCU/RS485_RXD: U2.1 (RO); also elsewhere on the board
/MCU/RS485_TE\~RE: U2.2 (~RE), U2.3 (DE); also elsewhere on the board
/MCU/RS485_TXD: U2.4 (DI); also elsewhere on the board
/MCU/SCL_1: J2.3, U1.6 (SCL); also elsewhere on the board
/MCU/SDA_1: J2.2, U1.5 (SDA); also elsewhere on the board
GND: C1.1, C2.2, C3.1, C4.2, C5.1, C6.2, C7.2, C8.1, C9.2, H2.1, H3.1, H4.1, J1.2, J2.4, J3.2, J4.3, J5.3, J6.3, U1.1 (E0), U1.2 (E1), U1.3 (E2), U1.4 (VSS), U1.7 (~WC), U2.5 (GND); also elsewhere on the board
unnamed: J7.1, U2.7 (B)
unnamed: J7.2, U2.6 (A)

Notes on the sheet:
FS1015CL flow sensors
MPX5010DP pressure sensors

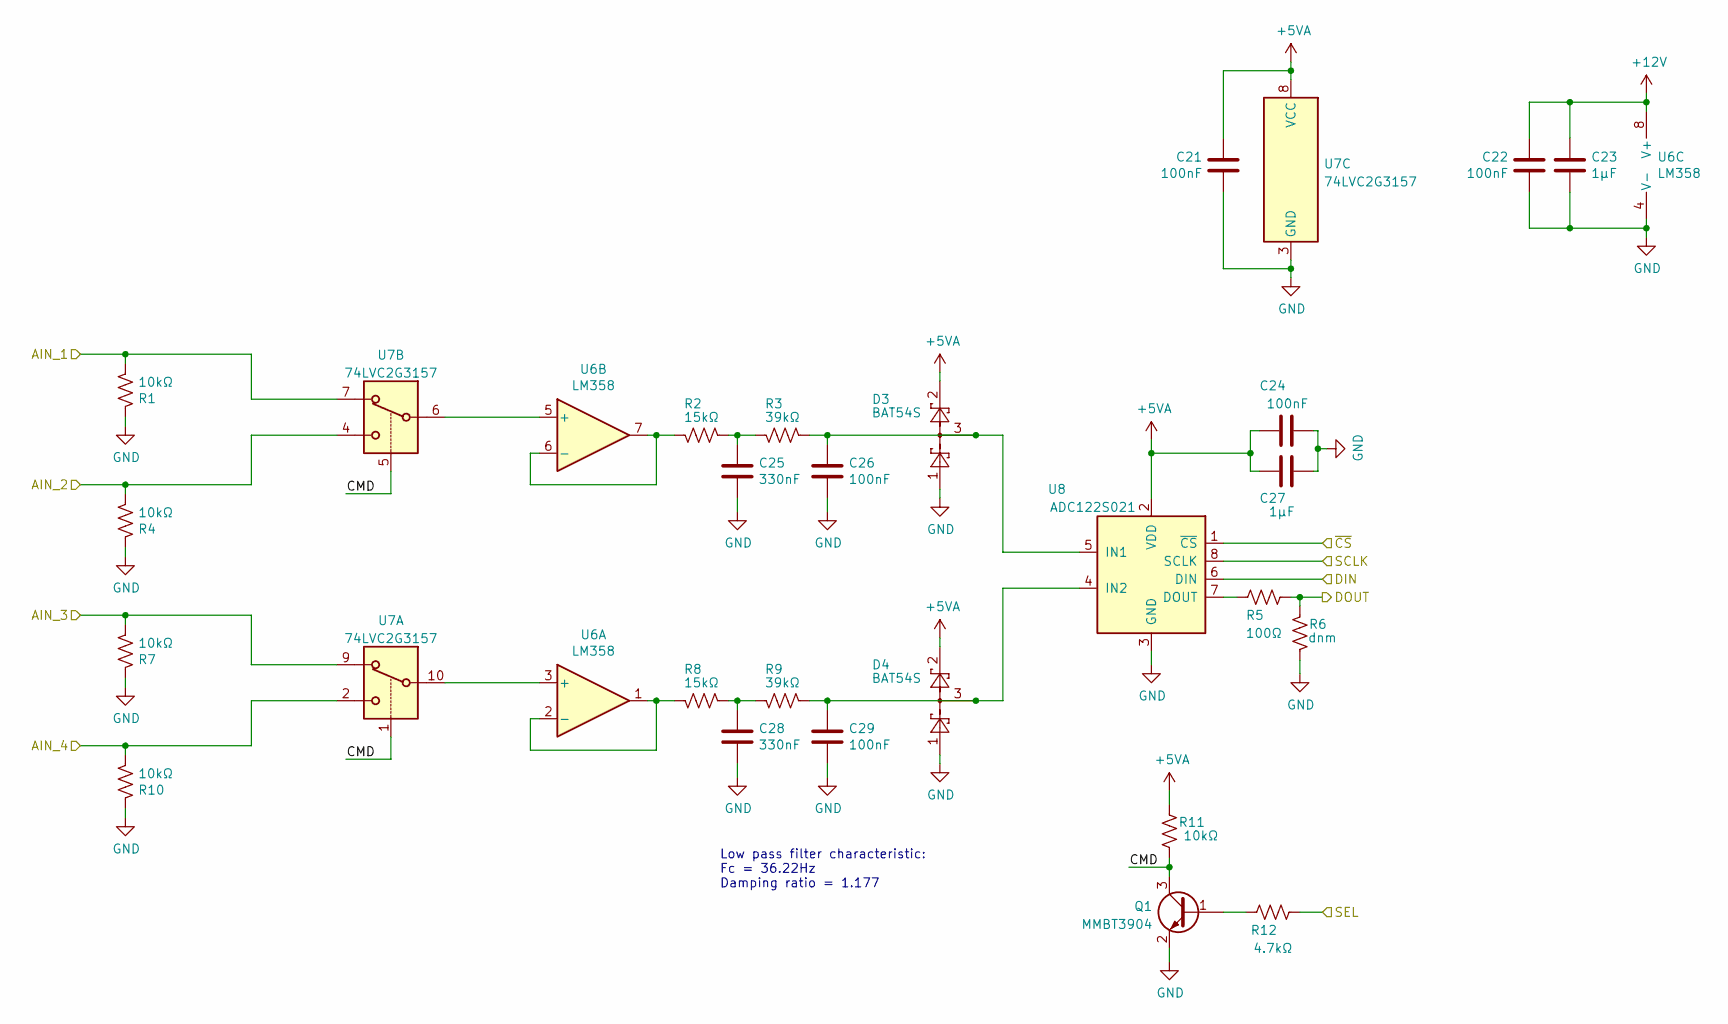
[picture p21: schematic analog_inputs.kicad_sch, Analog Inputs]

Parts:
C21, C22, C24, C26, C29: 100nF; C_0603_1608Metric_Pad1.08x0.95mm_HandSolder
C23, C27: 1μF; C_0603_1608Metric_Pad1.08x0.95mm_HandSolder
C25, C28: 330nF; C_0805_2012Metric_Pad1.18x1.45mm_HandSolder
D3, D4: BAT54S; SOT-23
Q1: MMBT3904; SOT-23
R1, R4, R7, R10, R11: 10kΩ; R_0805_2012Metric_Pad1.20x1.40mm_HandSolder
R2, R8: 15kΩ; R_0603_1608Metric_Pad0.98x0.95mm_HandSolder
R3, R9: 39kΩ; R_0603_1608Metric_Pad0.98x0.95mm_HandSolder
R5: 100Ω; R_0603_1608Metric_Pad0.98x0.95mm_HandSolder
R6: dnm; R_0805_2012Metric_Pad1.20x1.40mm_HandSolder
R12: 4.7kΩ; R_0603_1608Metric_Pad0.98x0.95mm_HandSolder
U6: LM358; SOIC-8_3.9x4.9mm_P1.27mm
U7: 74LVC2G3157; TSSOP-10_3x3mm_P0.5mm
U8: ADC122S021; VSSOP-8_3.0x3.0mm_P0.65mm

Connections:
+5VA: C21.2, C24.1, C27.1, D3.2, D4.2, R11.2, U7.8 (VCC), U8.2 (VDD); also elsewhere on the board
+12V: C22.2, C23.1, U6.8 (V+); also elsewhere on the board
/Analog input stage/AIN_1: R1.2, U7.7; also elsewhere on the board
/Analog input stage/AIN_2: R4.2, U7.4; also elsewhere on the board
/Analog input stage/AIN_3: R7.2, U7.9; also elsewhere on the board
/Analog input stage/AIN_4: R10.2, U7.2; also elsewhere on the board
/Analog input stage/CMD: Q1.3 (C), R11.1, U7.1, U7.5
/Analog input stage/DIN: U8.6 (DIN); also elsewhere on the board
/Analog input stage/DOUT: R5.2, R6.1; also elsewhere on the board
/Analog input stage/SCLK: U8.8 (SCLK); also elsewhere on the board
/Analog input stage/SEL: R12.2; also elsewhere on the board
/Analog input stage/~CS: U8.1 (~CS); also elsewhere on the board
GND: C21.1, C22.1, C23.2, C24.2, C25.2, C26.2, C27.2, C28.2, C29.2, D3.1, D4.1, Q1.2 (E), R1.1, R4.1, R6.2, R7.1, R10.1, U6.4 (V-), U7.3 (GND), U8.3 (GND); also elsewhere on the board
unnamed: C25.1, R2.1, R3.2
unnamed: C26.1, D3.3, R3.1, U8.5 (IN1)
unnamed: C28.1, R8.1, R9.2
unnamed: C29.1, D4.3, R9.1, U8.4 (IN2)
unnamed: Q1.1 (B), R12.1
unnamed: R2.2, U6.6 (-), U6.7
unnamed: R5.1, U8.7 (DOUT)
unnamed: R8.2, U6.1, U6.2 (-)
unnamed: U6.3 (+), U7.10
unnamed: U6.5 (+), U7.6

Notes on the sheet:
Low pass filter characteristic: Fc = 36.22Hz Damping ratio = 1.177

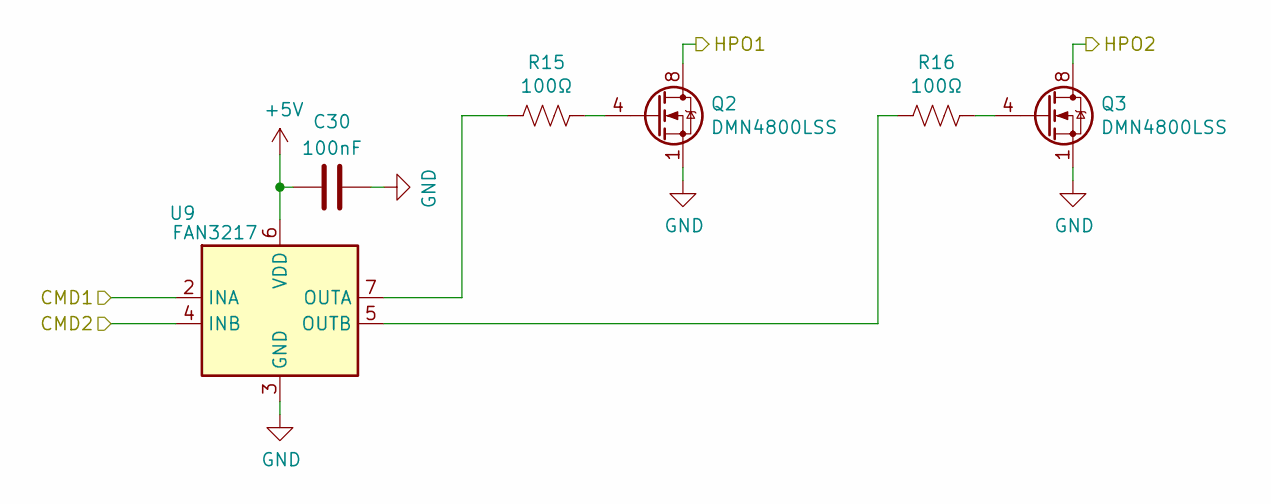
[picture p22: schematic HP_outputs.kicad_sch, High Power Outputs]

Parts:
C30: 100nF; C_0603_1608Metric_Pad1.08x0.95mm_HandSolder
Q2, Q3: DMN4800LSS; SOIC-8_3.9x4.9mm_P1.27mm
R15, R16: 100Ω; R_0603_1608Metric_Pad0.98x0.95mm_HandSolder
U9: FAN3217; SOIC-8_3.9x4.9mm_P1.27mm

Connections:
+5V: C30.1, U9.6 (VDD); also elsewhere on the board
/High power outputs/CMD1: U9.2 (INA); also elsewhere on the board
/High power outputs/CMD2: U9.4 (INB); also elsewhere on the board
/High power outputs/HPO1: Q2.5 (D), Q2.6 (D), Q2.7 (D), Q2.8 (D); also elsewhere on the board
/High power outputs/HPO2: Q3.5 (D), Q3.6 (D), Q3.7 (D), Q3.8 (D); also elsewhere on the board
GND: C30.2, Q2.1 (S), Q2.2 (S), Q2.3 (S), Q3.1 (S), Q3.2 (S), Q3.3 (S), U9.3 (GND); also elsewhere on the board
unnamed: Q2.4 (G), R15.1
unnamed: Q3.4 (G), R16.1
unnamed: R15.2, U9.7 (OUTA)
unnamed: R16.2, U9.5 (OUTB)

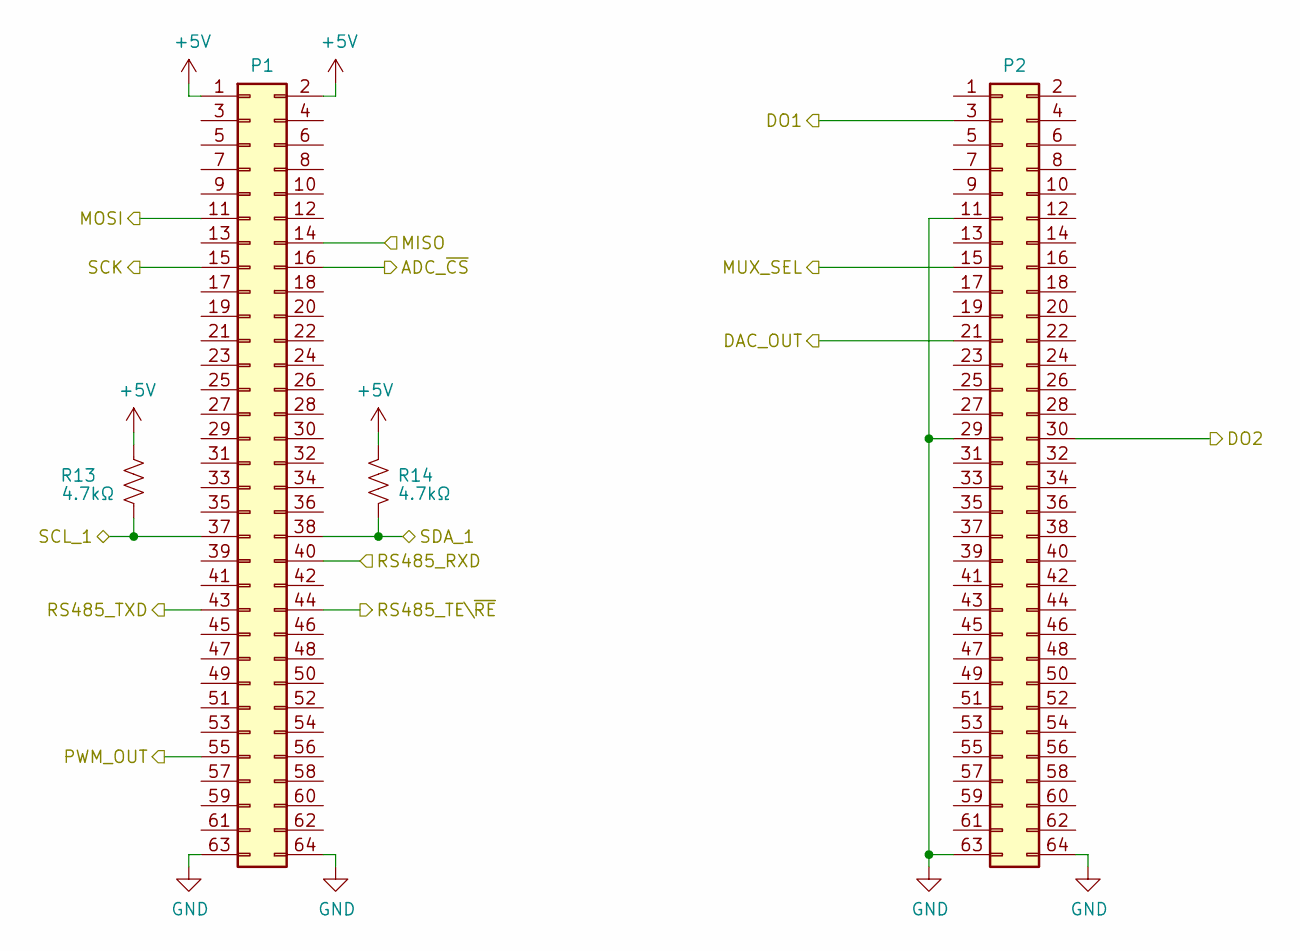
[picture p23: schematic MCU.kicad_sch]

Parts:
P1, P2: PinHeader_2x32_P2.54mm_Vertical
R13, R14: 4.7kΩ; R_0603_1608Metric_Pad0.98x0.95mm_HandSolder

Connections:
+5V: P1.1, P1.2, R13.2, R14.2; also elsewhere on the board
/Analog input stage/DIN: P1.11; also elsewhere on the board
/Analog input stage/DOUT: P1.14; also elsewhere on the board
/Analog input stage/SCLK: P1.15; also elsewhere on the board
/Analog input stage/SEL: P2.15; also elsewhere on the board
/Analog input stage/~CS: P1.16; also elsewhere on the board
/High power outputs/CMD1: P2.3; also elsewhere on the board
/High power outputs/CMD2: P2.30; also elsewhere on the board
/MCU/DAC_OUT: P2.21
/MCU/PWM_OUT: P1.55
/MCU/RS485_RXD: P1.40; also elsewhere on the board
/MCU/RS485_TE\~RE: P1.44; also elsewhere on the board
/MCU/RS485_TXD: P1.43; also elsewhere on the board
/MCU/SCL_1: P1.37, R13.1; also elsewhere on the board
/MCU/SDA_1: P1.38, R14.1; also elsewhere on the board
GND: P1.63, P1.64, P2.11, P2.29, P2.63, P2.64; also elsewhere on the board

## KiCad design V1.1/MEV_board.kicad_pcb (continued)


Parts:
C10, C11, C12, C16: 4.7μF; C_0805_2012Metric_Pad1.18x1.45mm_HandSolder
C13, C14, C15: 10μF; C_0805_2012Metric_Pad1.18x1.45mm_HandSolder
C17, C19: 330nF; C_0805_2012Metric_Pad1.18x1.45mm_HandSolder
C18, C20: 100nF; C_0603_1608Metric_Pad1.08x0.95mm_HandSolder
U3: TSR_1-2450; Converter_DCDC_TRACO_TSR-1_THT
U4: L78L12_SO8; SOIC-8_3.9x4.9mm_P1.27mm
U5: L78L05_SO8; SOIC-8_3.9x4.9mm_P1.27mm

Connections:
+5V: C13.2, C14.2, C15.2, U3.3 (Vout); also elsewhere on the board
+5VA: C20.2, U5.1 (OUT); also elsewhere on the board
+12V: C18.2, C19.2, U4.1 (OUT), U5.8 (IN); also elsewhere on the board
+24V: C10.2, C11.2, C12.2, C16.2, C17.2, U3.1 (Vin), U4.8 (IN); also elsewhere on the board
GND: C10.1, C11.1, C12.1, C13.1, C14.1, C15.1, C16.1, C17.1, C18.1, C19.1, C20.1, U3.2 (GND), U4.2 (GND), U4.3 (GND), U4.6 (GND), U4.7 (GND), U5.2 (GND), U5.3 (GND), U5.6 (GND), U5.7 (GND); also elsewhere on the board



Board: 2 copper layers, 66.0 x 124.7 mm, 75 parts (14 on the bottom side), 40 nets.

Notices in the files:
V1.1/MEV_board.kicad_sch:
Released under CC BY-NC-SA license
